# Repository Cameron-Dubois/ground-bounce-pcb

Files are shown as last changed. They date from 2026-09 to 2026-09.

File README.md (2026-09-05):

# Ground Bounce Demo PCB

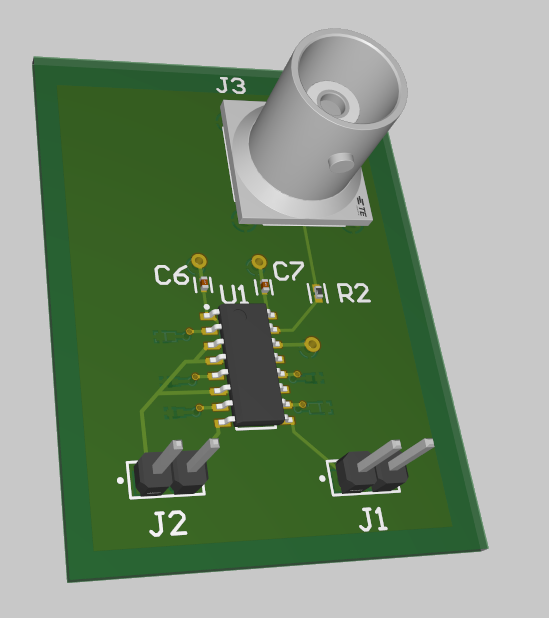
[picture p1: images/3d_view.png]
3D Board View


A 2-layer PCB designed to experimentally demonstrate ground bounce, a signal integrity effect caused by bondout lead inductance in IC packaging. Built for ECE173L (High Speed Digital Design) at UC Santa Cruz.

## What it does

Uses a 6-bit D flip-flop (CD74HCT174) to charge five load capacitors (Q0-Q4), then simultaneously discharges them into the ground plane on every clock cycle. An RC delay circuit drives the reset signal, creating repeating bounce events that can be observed on an oscilloscope through a COAX probe at Q5.

## My contribution

Led the Altium design work, including layout, routing, and Gerber generation for fabrication.

## Layout

| Top Layer | Bottom Layer |
|---|---|
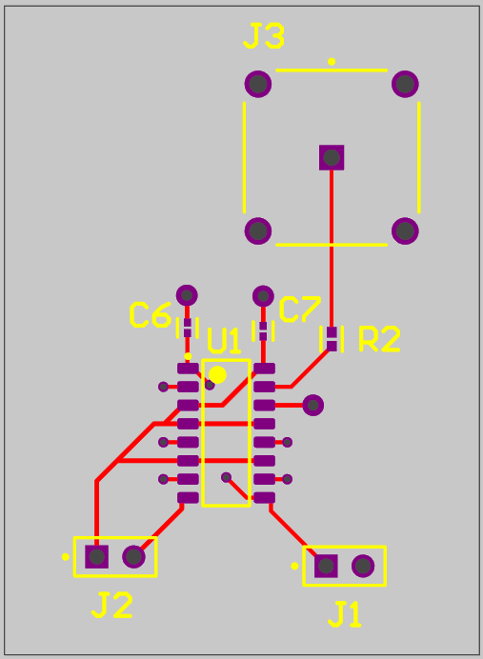
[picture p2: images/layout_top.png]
Top Layer
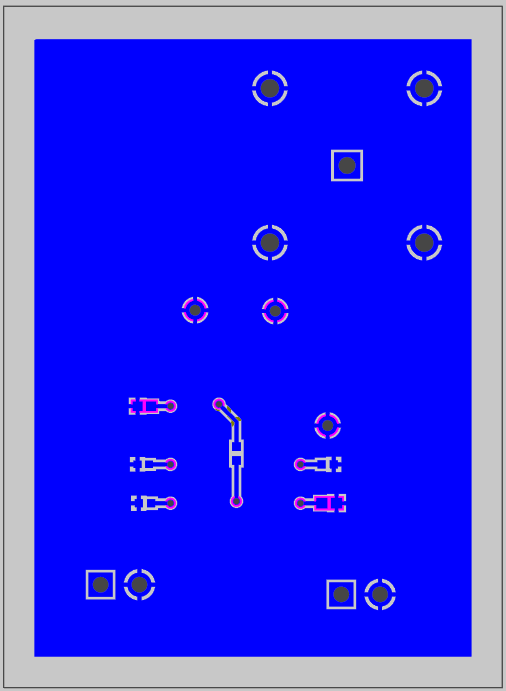
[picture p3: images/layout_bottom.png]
Bottom Layer
|  |  |

## Schematic

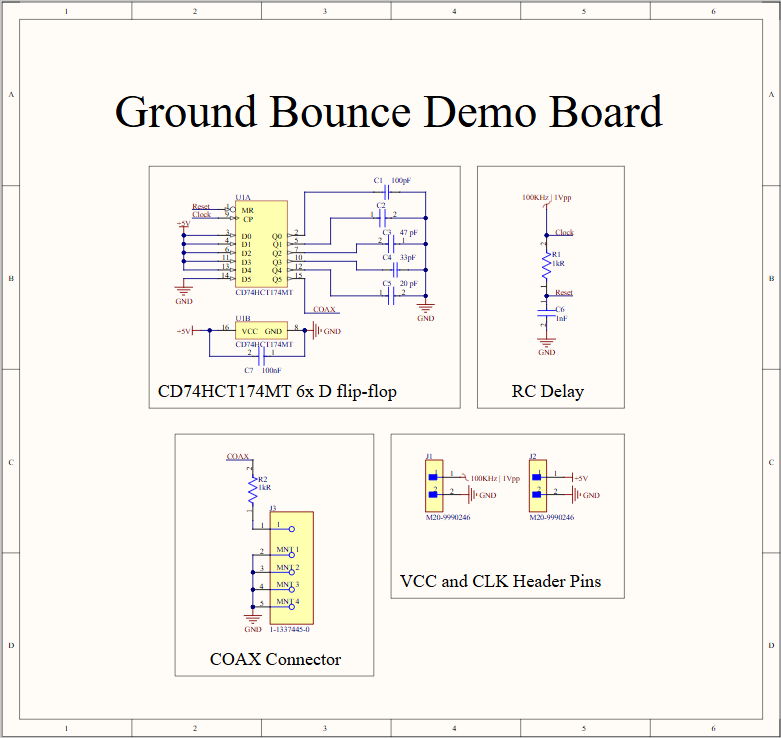
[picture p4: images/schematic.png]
Schematic


## Result

Due to board fabrication delays, the design was verified on breadboard rather than the finished PCB. The breadboard build worked as intended, producing a repeating ~40mV ground bounce spike matching the calculated time constant. A voltage regulator was mistakenly omitted from the design, so the bounce amplitude wasn't independently adjustable, but the effect itself was clearly observable.

Full write-up with oscilloscope captures and calculated bondout inductance is in [`ground_bounce_writeup.pdf`](ground_bounce_writeup.pdf).

## Files

- `PCB2.PcbDoc` — Altium source files
- `gerber/` — fabrication-ready Gerber files
- `images/` — schematic and layout renders
- `ground_bounce_writeup.pdf` — full report with measurements and analysis

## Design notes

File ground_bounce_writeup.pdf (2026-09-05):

Cameron Dubois

ECE 173 Spring 2025

1625287

Cyclical Ground Bounce Demo PCB

### 1. PCB Overview

This PCB is designed to demonstrate the commonly encountered phenomena in high

speed digital design known as Ground Bounce. It demonstrates this effect by using a 6

input D-Flip Flop that charges capacitors at Q0-Q4, then simultaneously dumping the

capacitors into the ground plane. It repeats this as the clock is fed through an RC delay

circuit as the master reset signal. This spec sheet provides an overview of the board

design and its use.

Item | Note
Board Size | 34mm x 44mm (rectangular)
Stack-Up | 2-Layer FR4, 1oz copper
Bottom Layer | Solid Ground Plane
Top Layer | Local Vcc pours(just used vias), Signals

### 2. Component List & Placement Details

Designator | Part/Package | Purpose | Placement Notes
U1 | CD74HCT174PW | 6 bit D-FF IC | Center of top layer for shortest q-via paths

C1-C5 | 0402 (100pF, 75pF, 47 pF, 33pF, 20 pF) | Load Capacitors for Q0-Q4 | Bottom layer, directly below Q pins
R2 | 0402 1kΩ | Q5 Pull down | Next to U1 pin 15
R1/C6 | 0402 1kΩ + 1nF | RC delay for reset | C6 next to pin 1, R1 on bottom layer under U1
C7 | 0402 100nF | VCC decoupling cap | Close t o VCC pin, through to ground plane
J1/J2 | 2 pin headers | Clock in, VCC in | Bottom Edge of board
J3 | SMA Edge Jack | Coax probe at q5 | Top edge of board

Note: A linear voltage regulator was mistakenly not included in our design, meaning the

ground bounce measured at the COAX cable is not seamlessly adjustable, although still

visible.

### 3. Electrical Specifications

Parameter | Typical
Supply Voltage (via 2 pin header) | +5.0V
Quiescent ICC | ≈ 5mA
Transient ICC (all Q low) | ≈ 35mA peak
Clock Input | 100kHz Square, 5Vpp, 50% duty cycle
Reset Pulse Width (τ) | 1ms
Expected Bounce Spike | ≈ 40mV/2ns at coax cable

### 4. Ground Bounce Measurement Technique

-Set DC power supply to +5V, and attach to the J2 VCC pin headers at the bottom left of

the board.

-Set waveform generator to a 100kHz and 5Vpp square wave with a 50% duty cycle to

act as out clock.

-Attatch oscilloscope to the coax jack at Q5, ensure 50Ω input impedance.

-The circuit should already be functioning! The oscilloscope should be showing a

repeating spike in voltage relative to ground at the coax output. This spike repeats with

respect to the time constant, τ, of our RC delay circuit.

Expected Output:

Note: Unfortunately due to the board delays we decided to move forward with the

project using a bread board version of our circuit. The circuit did function as we

intended, giving us the output seen in figure 4-1. Checking the clock and reset pins with

a probe we also confirmed that they were both getting a fairly clean square wave, with

the master reset getting the signal delayed by the RC circuit.

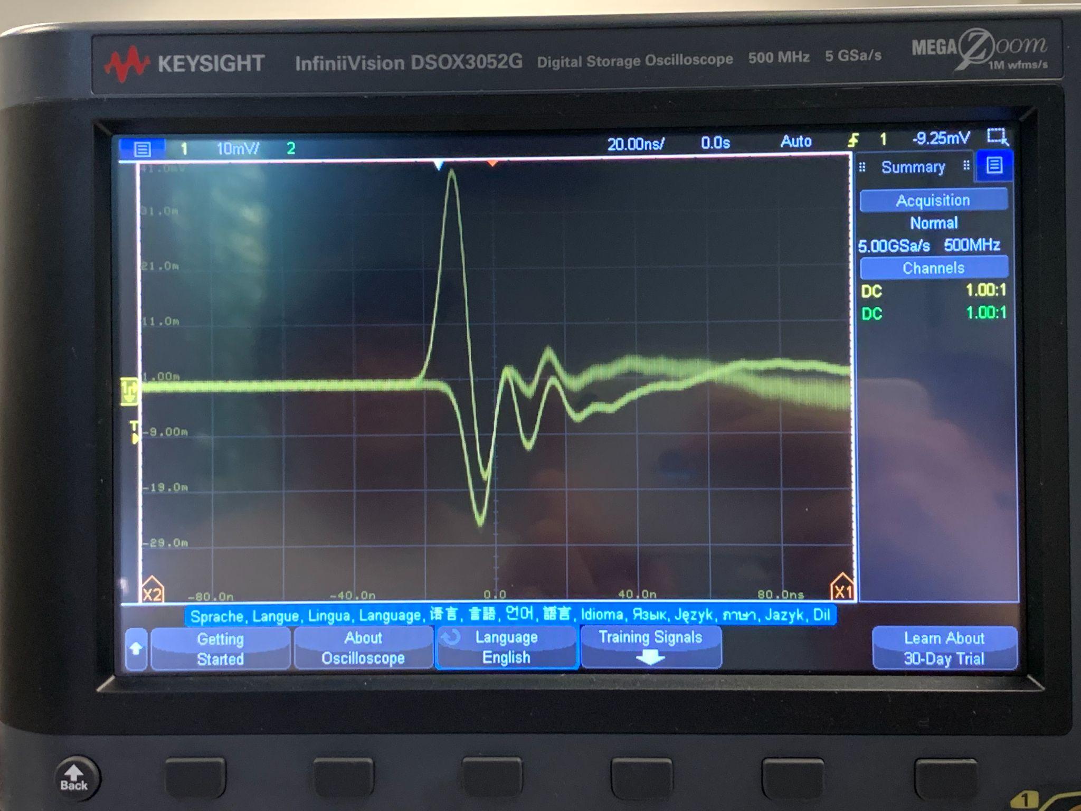
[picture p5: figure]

Figure 4-1: Ground Bounce Spike (measured at COAX)

A clear spike in voltage seen at ground.

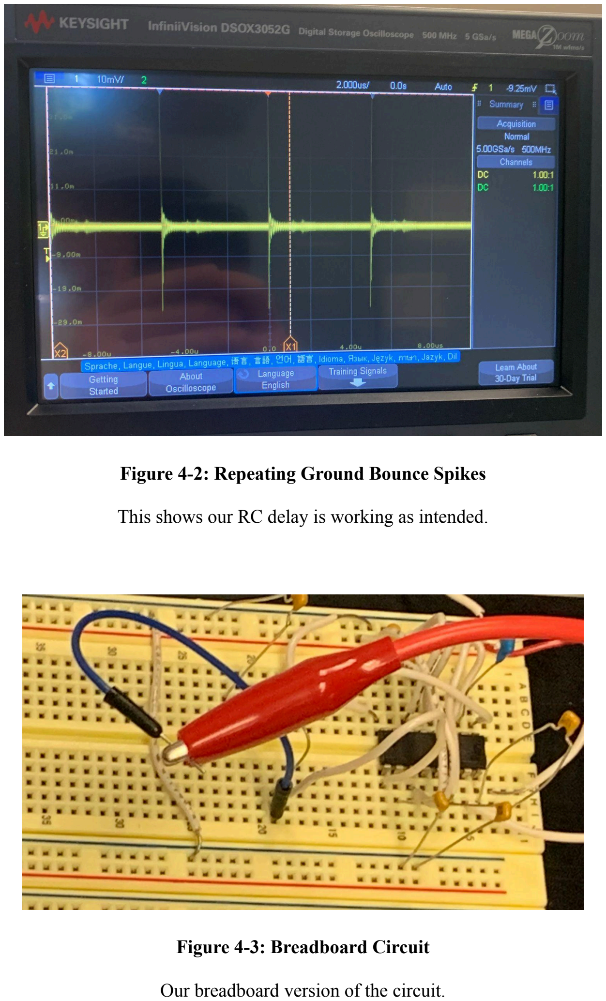
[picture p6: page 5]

Figure 4-2: Repeating Ground Bounce Spikes

This shows our RC delay is working as intended.

Figure 4-3: Breadboard Circuit

Our breadboard version of the circuit.

### 5. Schematic and Layout

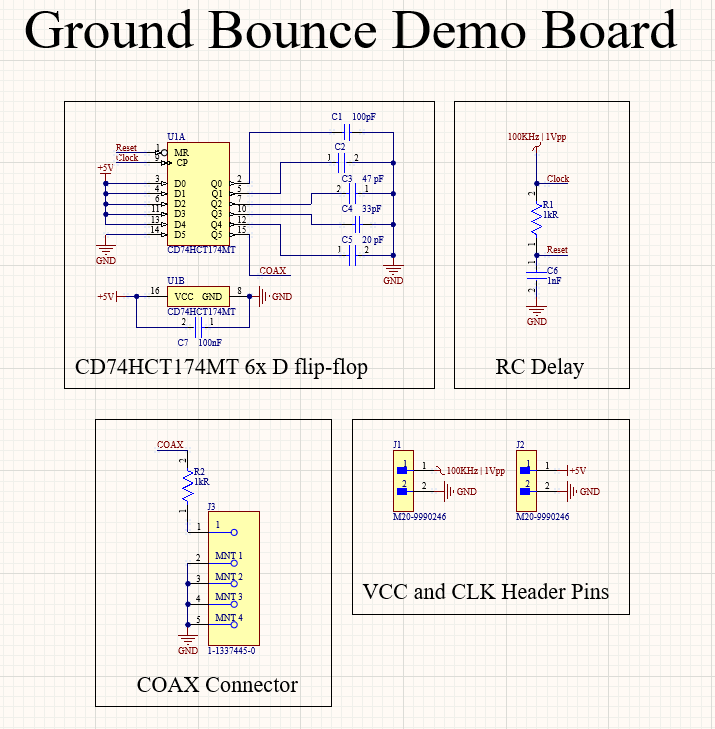
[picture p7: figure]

Figure 5-1: Schematic

Design includes a decoupling capacitor between the VCC and GND pins of U1 to limit

noise. The RC delay introduces a delay with a time constant of 1ms, allowing time for

the capacitors at Q0-Q4 to charge up before the clock signal reaches the master reset pin.

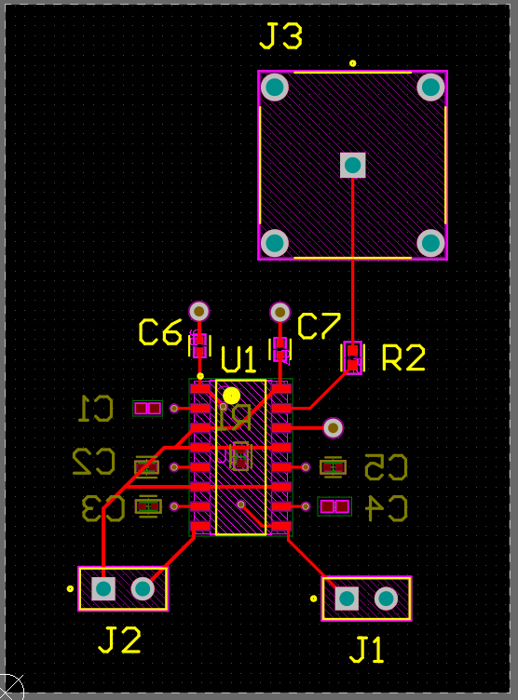
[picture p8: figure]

Figure 5-2: PCB Layout (top layer)

This Layer Contains the main flip flop IC itself. The headers were placed at the bottom

of the board to make the board feel a bit more organized while keeping trace length low.

Placing C1-C5 on the bottom layer allowed for easier access for VCC and the clock to the

pins that needed them.

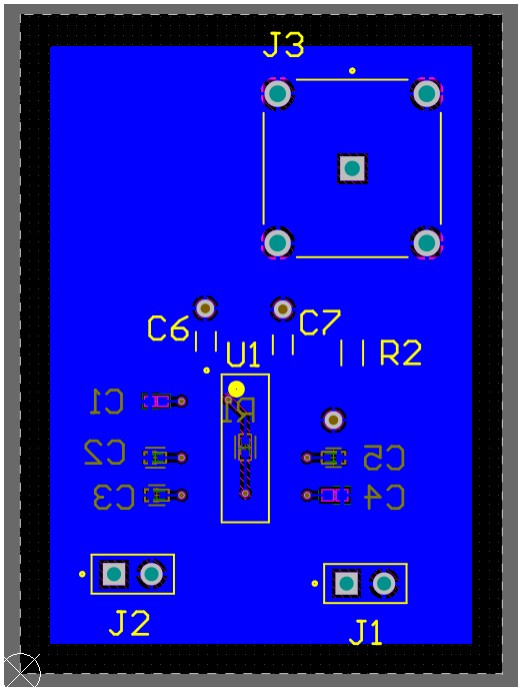
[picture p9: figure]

Figure 5-3: PCB Layout (bottom layer)

This layer contains a ground plane for the board, as well as the capacitors for Q0-Q4 and

the resistor for the RC delay circuit.

### 6. Project Questions

a) Bondout Inductance
Can be calculated using the formula L = | .

Vbounce

di
dt
Our measured Vbounce ≈ 40mV.

= slew rate ≈15ma/ns di
dt
L ≈2.67nH

This is quite a bit lower than the typical 5-25nH

b) Edge speed before integrity failure

The faster the edge the higher the slew rate, which increases inductive voltage

drops on Ground and VCC corresponding to the equation seen in question a. The

typical rise/fall times of this family of ICs is ~2-6ns. Any edges faster than 2ns is

where signal integrity issues would begin to appear. A higher from edge di
dt
speeds 1ns or faster are highly likely to see ground bounce.
c) Other Bondout Inductances

The other IC pins do have bondout inductance, of them the most likely to

require consideration are the pins at VCC, CLK/RST and I/O pins.

Rapid current draw when switching can cause a voltage dip in VCC

which could reduce logic high signals. At the I/O pins fast transitions

can cause ringing or crosstalk, and is even more important if the pin is driving a long trace. At the clock and reset pins delays may be

introduced, and it could lead to setup and hold time violations

d) Separate Analog and Digital Grounds

Digital switching can cause noisy currents in ground, these fast signals cause a

high which leads to things like ground bounce. Analog circuits rely di
dt
on a stable ground to reference for accuracy, meaning if they shared a

ground the analog signals could be corrupted by the noise created by the

digital signals. Keeping separate grounds in a mixed signal system can

help to prevent digital signals effects on ground from interfering with the

integrity of the analog signals.

e) Multiple Power and Ground pins

Using multiple pins for power or ground can help improve bondout inductance.

Having more pins means more parallel paths for the signal to travel through

leading to lower total inductance, in turn reducing ground bounce and voltage

drops. In higher speed digital ICs pins can draw significantly more current,

having multiple paths for the current to flow allows a higher total ICC without

exceeding any one pins limits. It can also allow for greater flexibility in the

layout.

### 7. Group Contribution Statement

Member | Tasks Contributed To
Cameron Dubois | PCB Layout, Routing, Gerber generation/submission
Calvin He | Schematic, RC delay calculations, finding correct parts in manufacturer part search
Collaboration | Breadboard building, ground bounce observation, troubleshooting, any in lab work

Note: I would argue that neither one of us did any one chunk of the project in its entirety

on our own. There was constant collaboration and checking info or work with the other.

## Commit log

2026-09-05 Initial commit: ground bounce PCB project
    [PCB2.PcbDoc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]
2026-09-05 Fix schematic file name
